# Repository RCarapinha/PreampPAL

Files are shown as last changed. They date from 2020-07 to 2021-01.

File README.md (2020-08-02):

# PreampPAL

Project done in 3th year of Masters.

# Description

The goal of this team is to perform a low-noise pre-amplifier that amplifies the needle signal to a line level signal. To accomplish this we started by understanding what was a preamplifier for a record player, namely, what was a preamplifier with reverse RIAA equalization that would amplify the needle signal to a line level signal.

So this team is responsible for the electronics of the turntable audio. This task consists of manipulating low-value and very sensitive voltages. 

# 1st Step: Tests and Simulation

Having said this, we started the search for a preamplifier that corresponded to our needs, i.e. a preamplifier that applied what was described above and low noise (because the values received by the needle are very low).

We chose a range of preamplifiers and set out for the simulation phase using the LTSpice program.

We performed several simulations in LTSpice in terms of noise and equalization in order to choose the best pre-amplifier. At the end of this phase we started to develop the circuit.

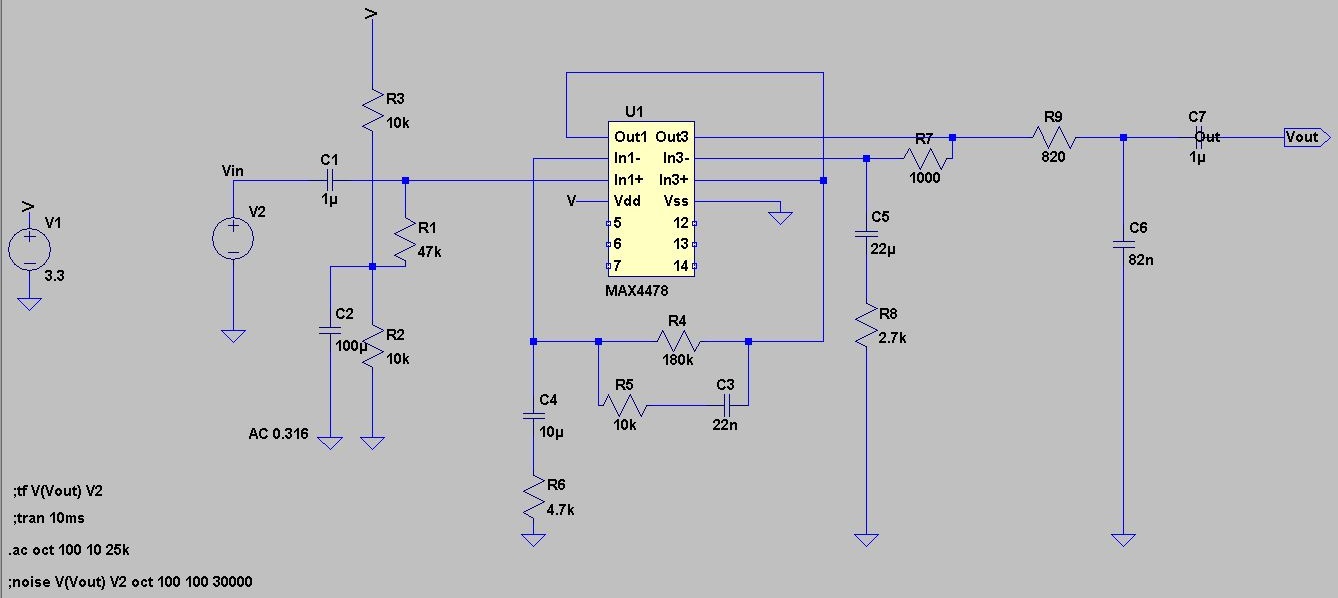
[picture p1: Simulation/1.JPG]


# 2nd Step: Breadboard Tests

The first test to be performed was to make sure that the voltage regulator (low noise) correctly converted the value from 5V to 3.3V, and this test was successful. The second test was to verify the amplification and RIAA equalization. For this, a weak signal was applied to the input and we compared the output values obtained with the theoretical output values.

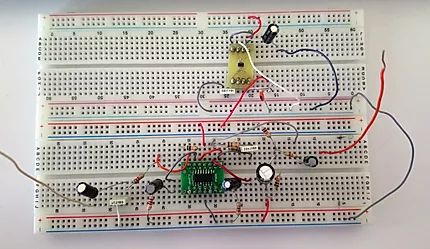
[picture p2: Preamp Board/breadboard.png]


# 3rd Step: PCB Design

After we carried out the tests and validated the operation of the circuit, the next step of the team was to develop the PCB (in EAGLE software) so that we could finish the work.

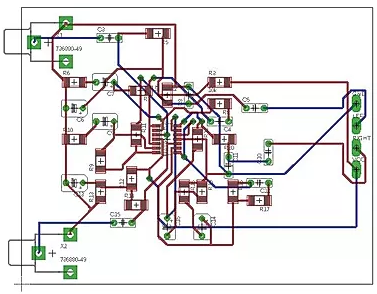
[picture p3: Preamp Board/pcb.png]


# 4rd Step: Final Work

Once the PCB has been designed, we start to build the board and assemble the components on it, something that must be done with great care to avoid errors or noise. Finally, we tried to isolate the whole board, for a better functioning.

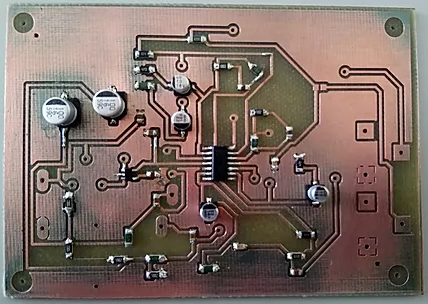
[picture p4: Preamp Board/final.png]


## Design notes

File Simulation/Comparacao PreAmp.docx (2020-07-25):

Comparação de Pré Amplificadores:

- Circuito:

Comparar entre 3 pré-amplificadores em termos de ganho, equalização RIAA, ruído, impedância de saída e preço e descobrir qual o mais viável.

- Circuitos Utilizados:
  - Bruno:

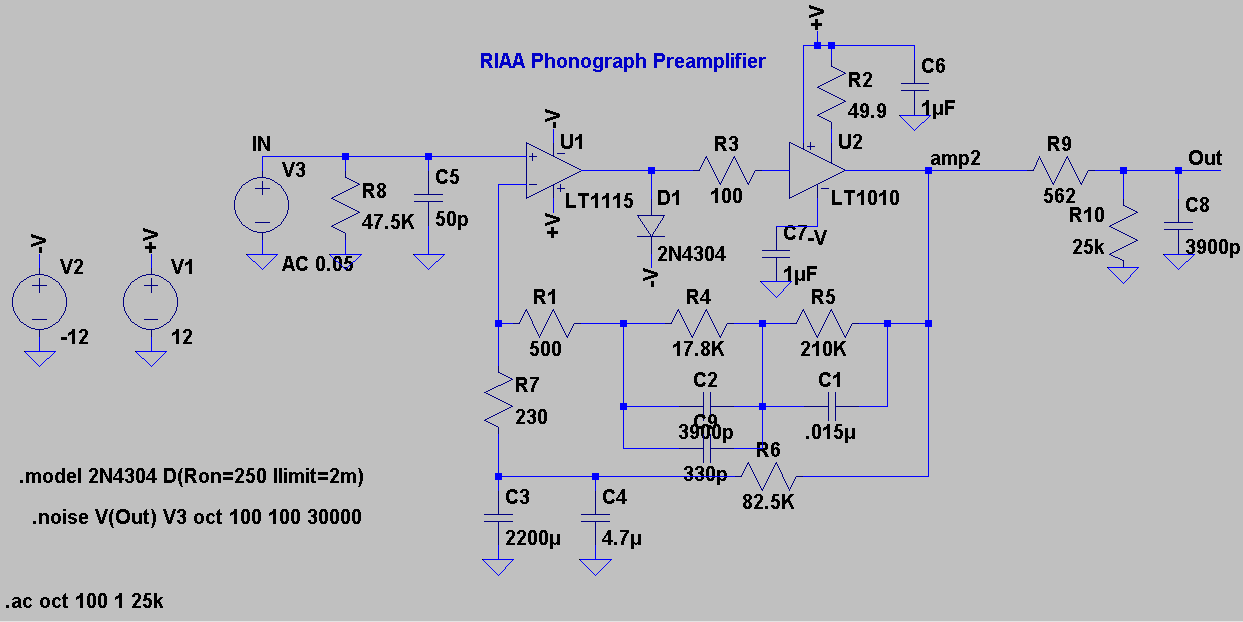
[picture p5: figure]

  - Carapinha:

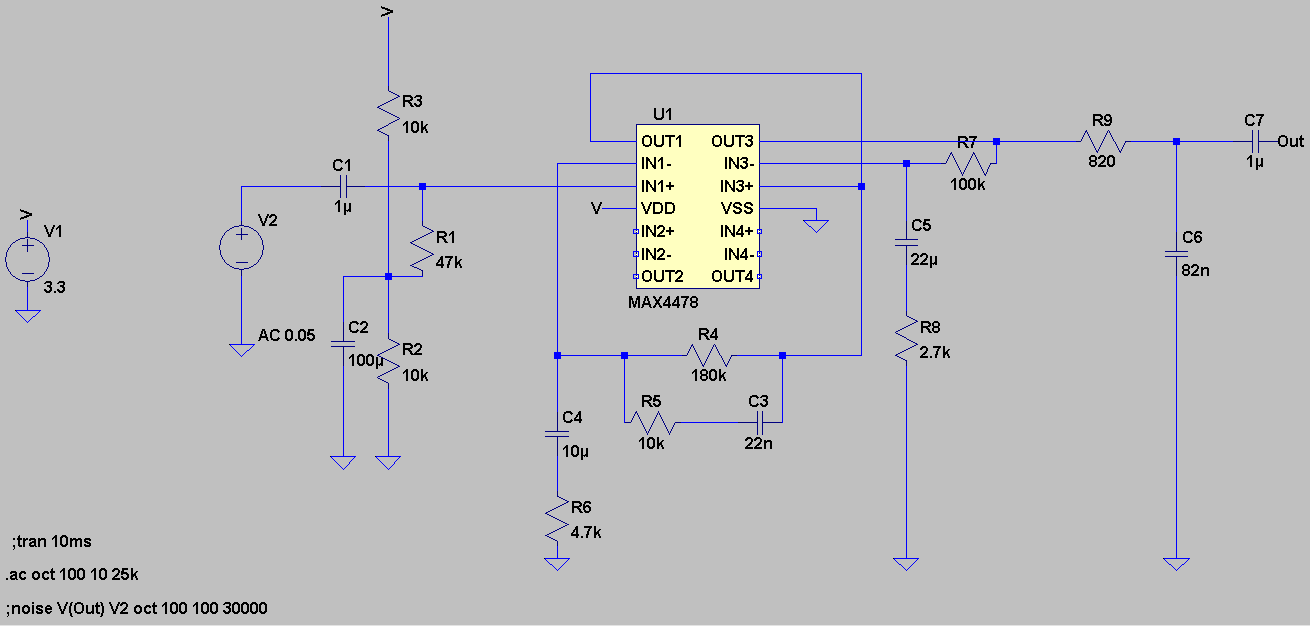
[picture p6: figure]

  - Gui:

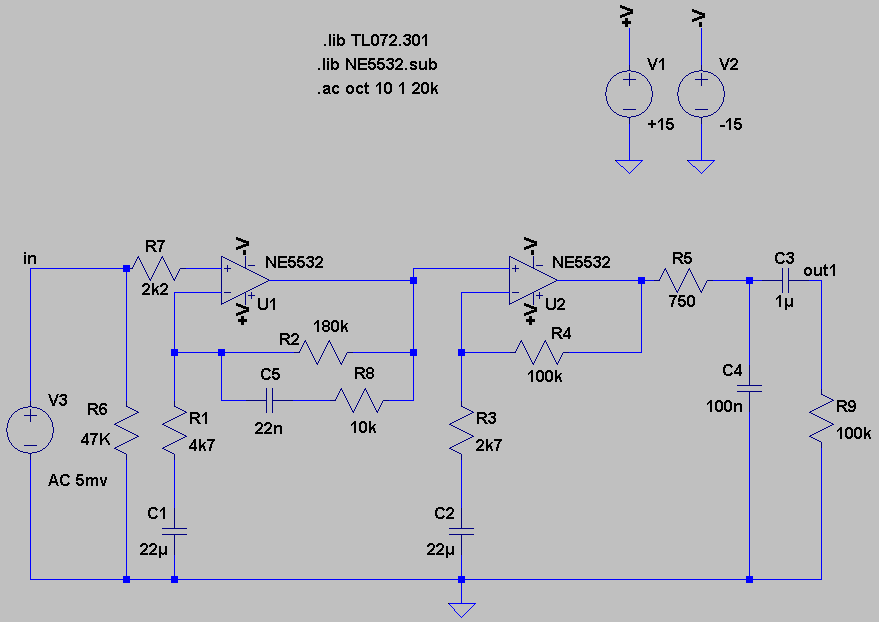
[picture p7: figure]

- RIAA:
  - Bruno:

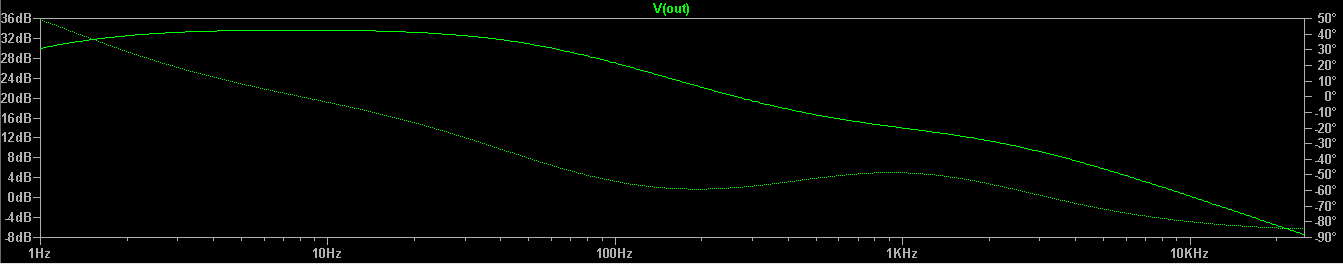
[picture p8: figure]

  - Carapinha:

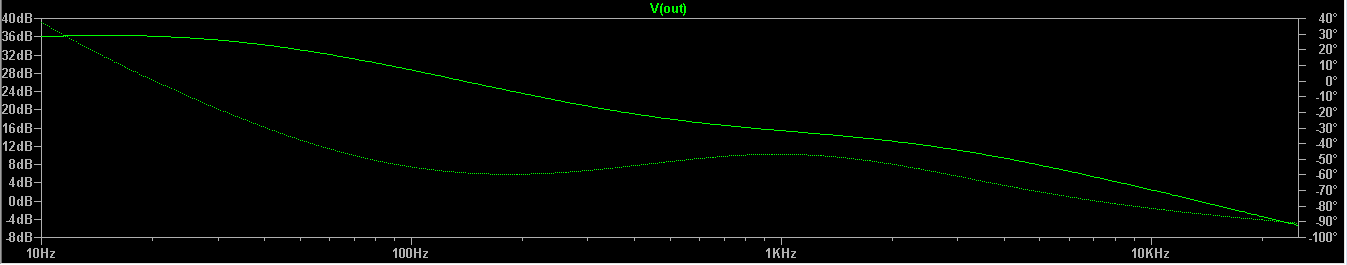
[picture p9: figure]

  - Gui:

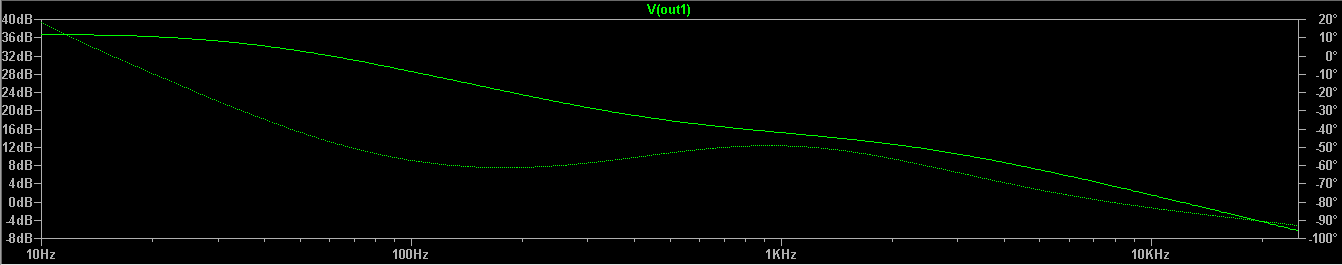
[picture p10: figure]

- Ruído:
  - Bruno:

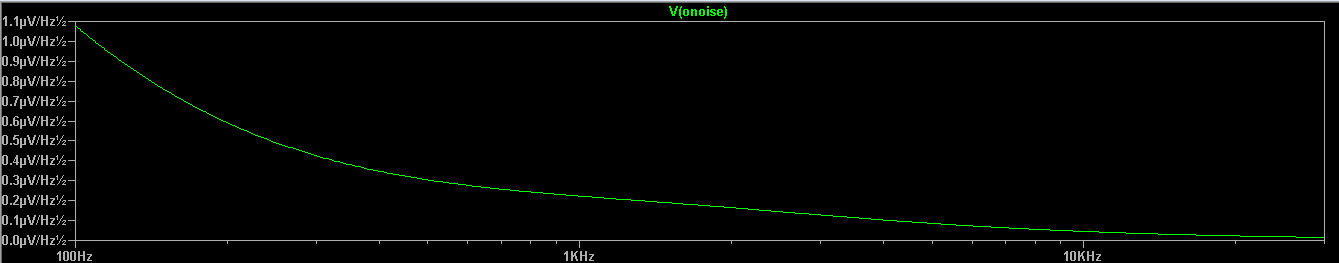
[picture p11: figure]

  - Carapinha:

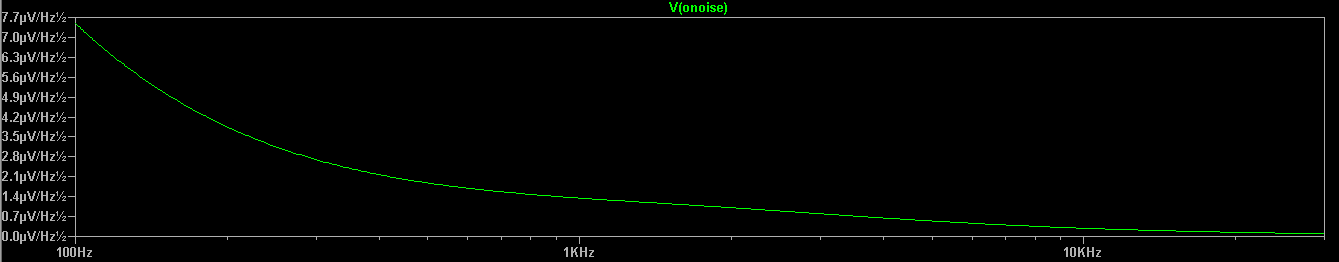
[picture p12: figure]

  - Gui:

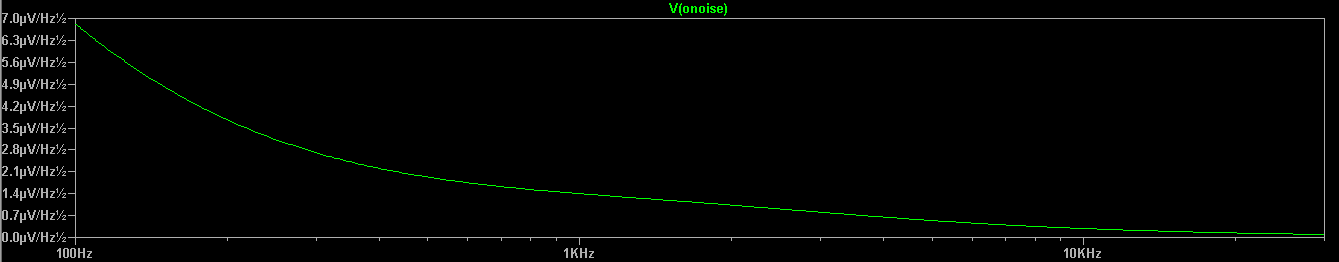
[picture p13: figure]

- Impedância de Saída:

Para fazer isto, colocámos uma fonte de corrente na saída e medimos a relação entre a tensão e a corrente.

  - Bruno:

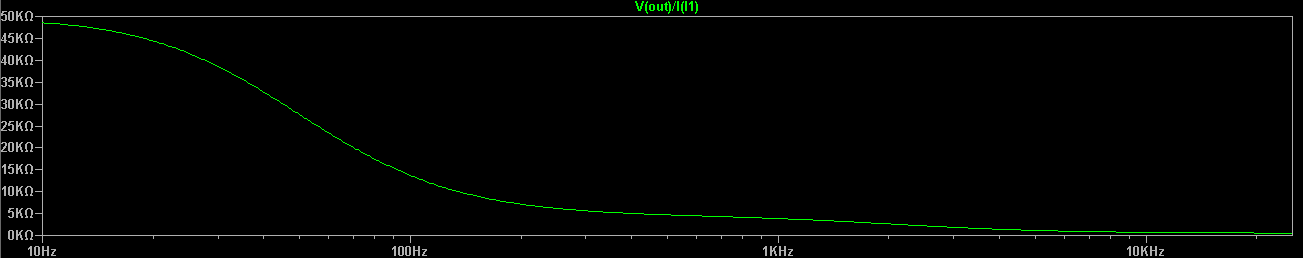
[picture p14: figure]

  - Carapinha:

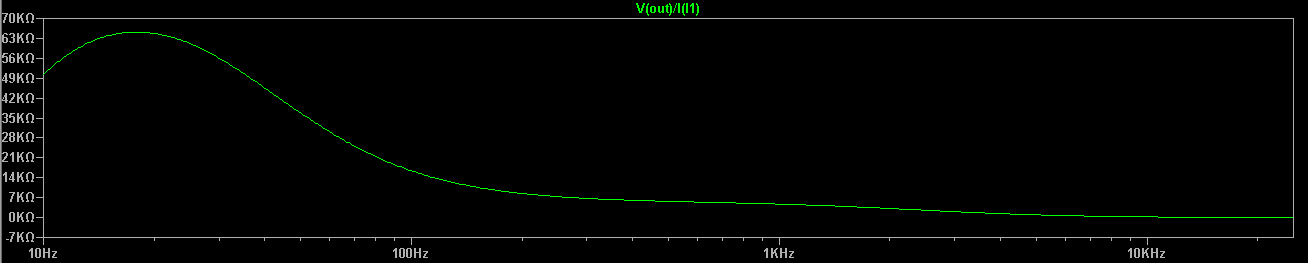
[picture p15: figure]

  - Gui:

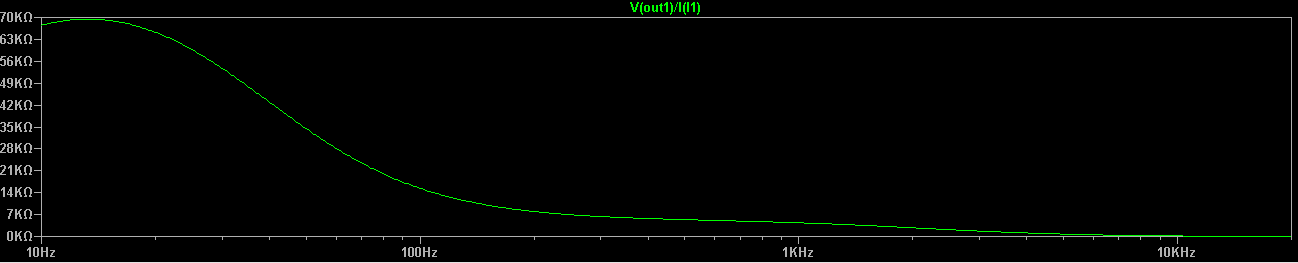
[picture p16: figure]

- Tensões Necessárias:
  - Bruno:

Tensões simétricas de 12V.

  - Carapinha:

Tensão única de 3.3V.

  - Gui:

Tensão simétricas de 15V.

- Preço:

Foram considerados os preços mais caros da loja DigiKey.

  - Bruno:

Componentes | Quantidade | Preço Unidade | Preço Total
R | 10 | 0,04 | 0,4
C | 13 | 0,2 | 2,6
LT1115 | 1 | 5,82 | 5,82
LT1010 | 1 | 4,57 | 4,57
Rail Splitter | 1 | - | -
2N4304 | 1 | - | -

Preço Total: 13,39€ (Faltam 2 componentes)

  - Carapinha:

Componentes | Quantidade | Preço Unidade | Preço Total
R | 9 | 0,04 | 0,36
C | 10 | 0,2 | 2
MAX4478 | 1 | 3,24 | 3,24
MAX8877EUK33 | 1 | 1,49 | 1,49

Preço Total: 7,09€

  - Gui:

Componentes | Quantidade | Preço Unidade | Preço Total
R | 9 | 0,04 | 0,36
C | 5 | 0,2 | 1
NE5532 | 1 | 1,26 | 1,26
Rail Splitter | 1 | - | -

Preço Total: 2,62€ (Falta 1 componente)

Os 3 circuitos precisam como é óbvio de um transformador de baixo ruído.

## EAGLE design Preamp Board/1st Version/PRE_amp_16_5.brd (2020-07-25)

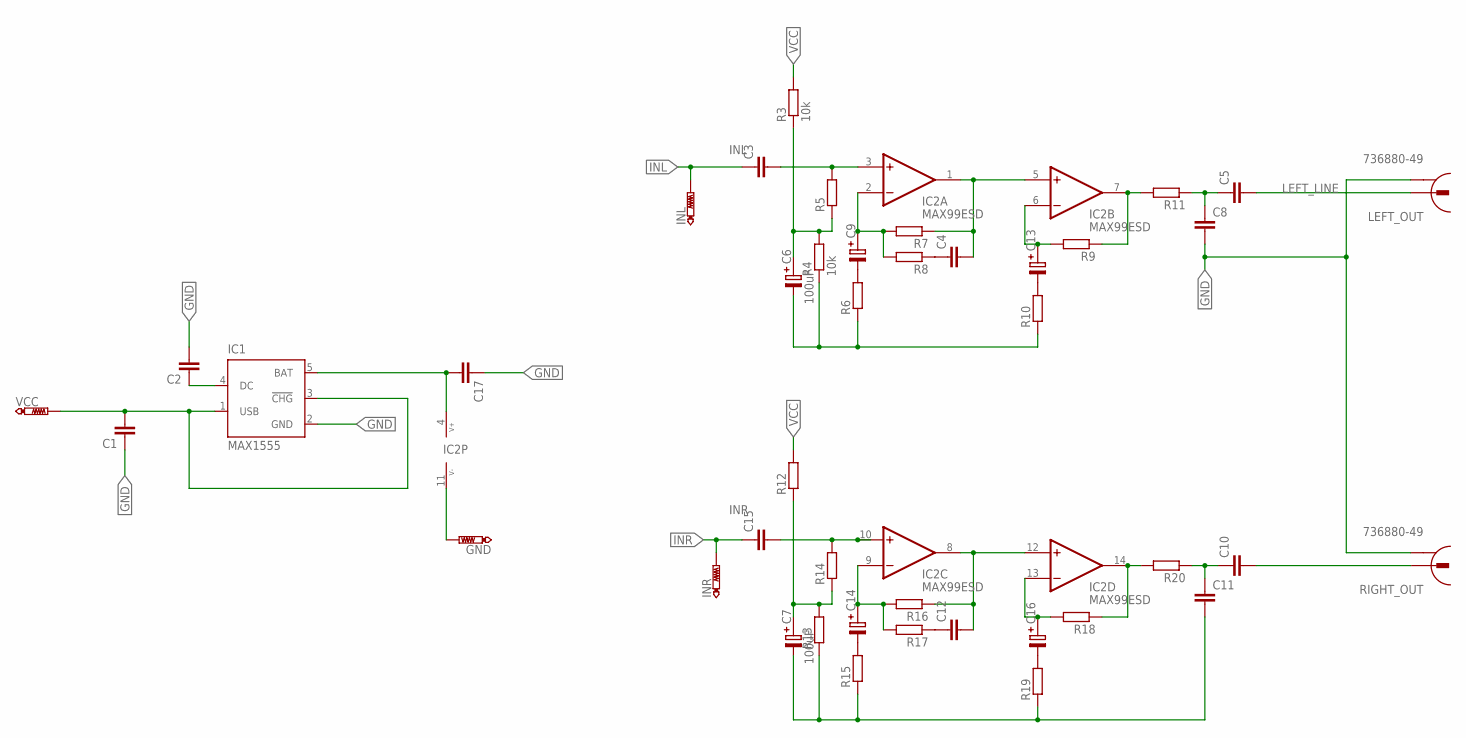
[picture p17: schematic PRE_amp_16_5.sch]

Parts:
C1, C2, C3, C4, C5, C8, C10, C11, C12, C15, C17: C-EUC0805; C0805
C6, C7: 100uF; SV-D
C9, C13, C14, C16: C-PR-SMD-SV-B; SV-B
GND: PTR1PAD1-13Y; P1-13Y
IC1: MAX1555; SOT23-5L
IC2: MAX99ESD; SO14
INL: PTR1PAD1-13Y; P1-13Y
INR: PTR1PAD1-13Y; P1-13Y
LEFT_OUT: 736880-49
R3, R4: 10k; R1206
R5, R6, R7, R8, R9, R10, R11, R12, R13, R14, R15, R16, R17, R18, R19, R20: R-EU_R1206; R1206
RIGHT_OUT: 736880-49
VCC: PTR1PAD1-13Y; P1-13Y

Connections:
GND: C1.1, C2.2, C6.-, C7.-, C8.2, C11.2, C17.1, GND.1, IC1.2 (GND), IC2.11 (V-), LEFT_OUT.2, R4.1, R6.1, R10.1, R13.1, R15.1, R19.1, RIGHT_OUT.2
INL: C3.1, INL.1
INR: C15.1, INR.1
LEFT_LINE: C5.2, LEFT_OUT.1
unnamed: C3.2, IC2.3 (+IN), R5.2
unnamed: C6.+, R3.1, R4.2, R5.1
unnamed: C15.2, IC2.10 (+IN), R14.2
unnamed: C7.+, R12.1, R13.2, R14.1
unnamed: IC2.7 (OUT), R9.1, R11.2
unnamed: C9.-, R6.2
unnamed: C4.1, R8.1
unnamed: C12.1, R17.1
unnamed: C9.+, IC2.2 (-IN), R7.2, R8.2
unnamed: C13.-, R10.2
unnamed: C5.1, C8.1, R11.1
unnamed: C14.-, R15.2
unnamed: C13.+, IC2.6 (-IN), R9.2
unnamed: C1.2, IC1.1 (USB), IC1.3 (!CHG), VCC.1
unnamed: C12.2, IC2.8 (OUT), IC2.12 (+IN), R16.1
unnamed: C14.+, IC2.9 (-IN), R16.2, R17.2
unnamed: C16.-, R19.2
unnamed: IC2.14 (OUT), R18.1, R20.2
unnamed: C4.2, IC2.1 (OUT), IC2.5 (+IN), R7.1
unnamed: C16.+, IC2.13 (-IN), R18.2
unnamed: C17.2, IC1.5 (BAT), IC2.4 (V+)
unnamed: C2.1, IC1.4 (DC)
unnamed: C10.2, RIGHT_OUT.1
NS2: C10.1, C11.1, R20.1
VCC: R3.2, R12.2

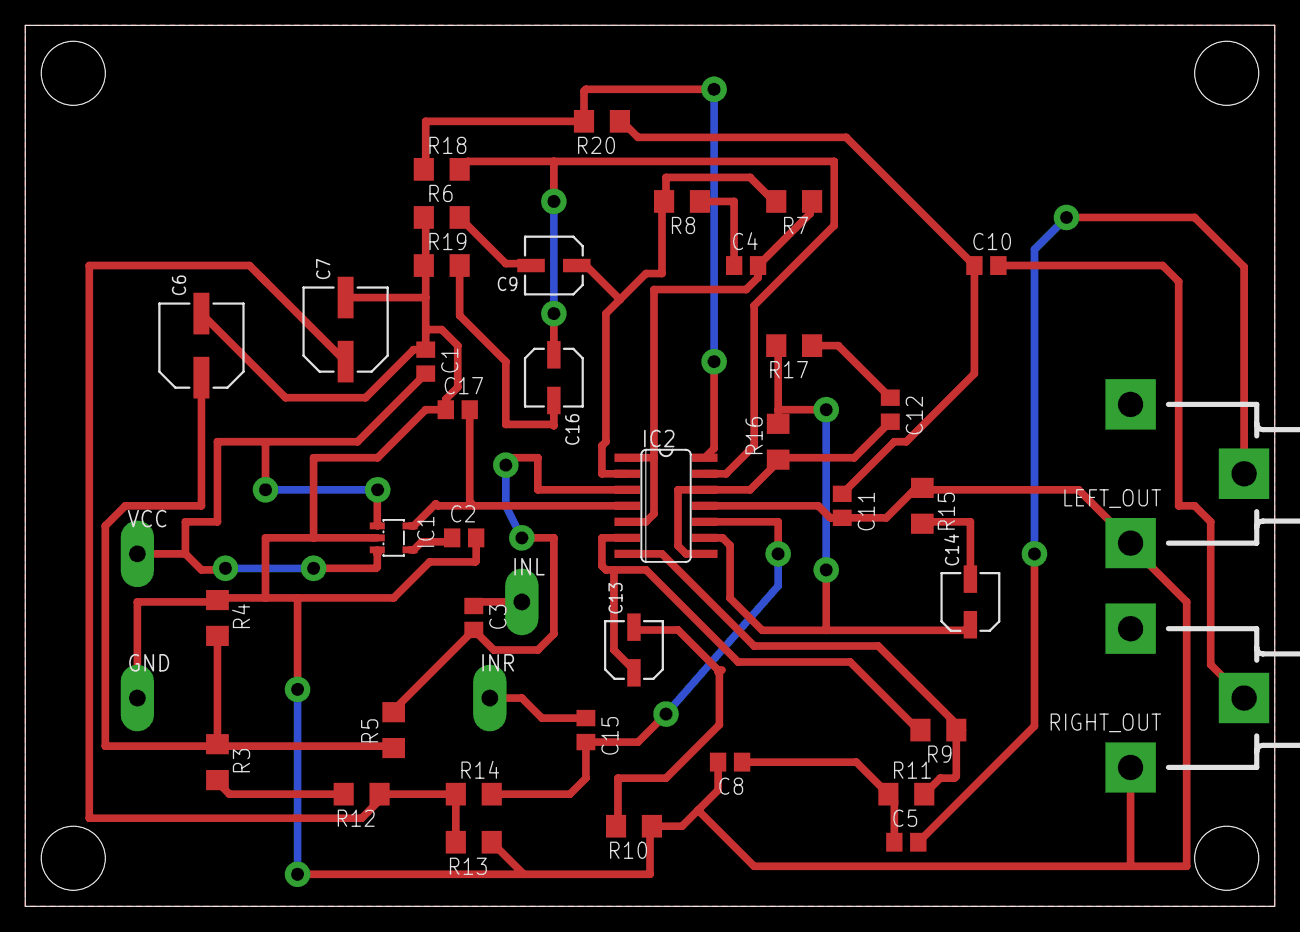
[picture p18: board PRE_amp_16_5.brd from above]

Board: 2 copper layers, 99.1 x 69.9 mm, 43 parts (0 on the bottom side), 29 nets.

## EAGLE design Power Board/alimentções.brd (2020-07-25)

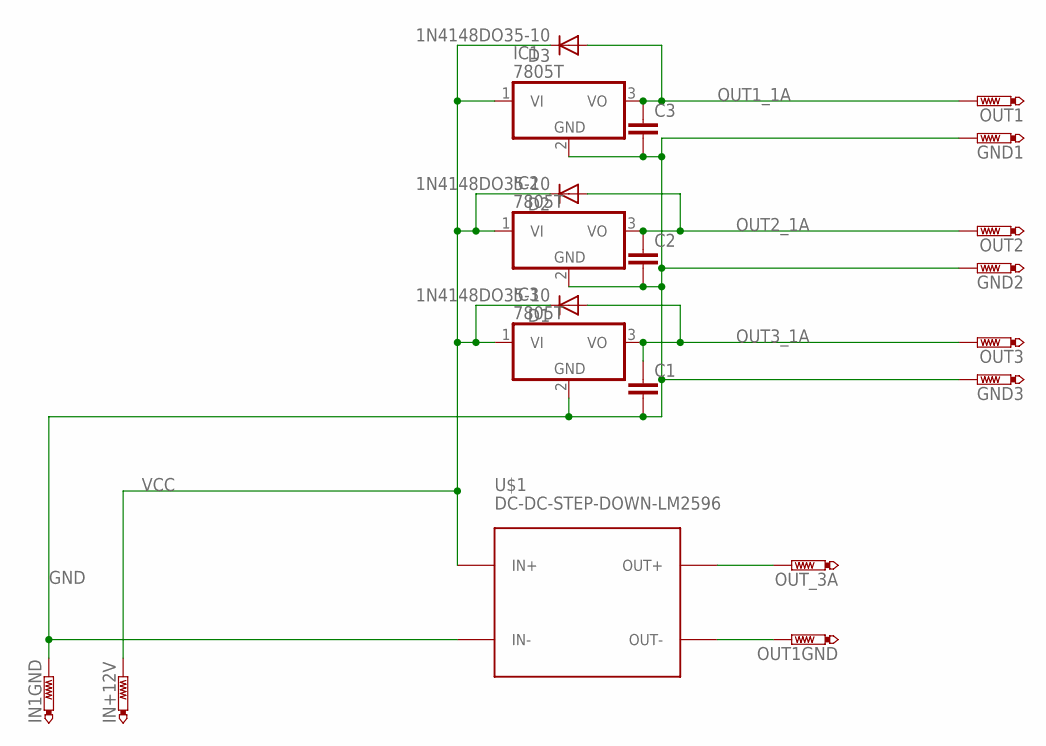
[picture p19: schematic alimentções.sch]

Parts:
C1, C2, C3: C-EU050-035X075; C050-035X075
D1, D2, D3: 1N4148DO35-10; DO35-10
GND1, GND2, GND3: PTR1PAD1-13Y; P1-13Y
IC1, IC2, IC3: 7805T; TO220H
IN1GND: PTR1PAD1-13Y; P1-13Y
IN+12V: PTR1PAD1-13Y; P1-13Y
OUT1, OUT1GND, OUT2, OUT3: PTR1PAD1-13Y; P1-13Y
OUT_3A: PTR1PAD1-13Y; P1-13Y
U$1: DC-DC-STEP-DOWN-LM2596

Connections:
GND: C1.2, C2.2, C3.2, GND1.TP, GND2.TP, GND3.TP, IC1.2 (GND), IC2.2 (GND), IC3.2 (GND), IN1GND.TP, U$1.IN-
unnamed: OUT1GND.TP, U$1.OUT-
unnamed: OUT_3A.TP, U$1.OUT+
OUT1_1A: C3.1, D3.A, IC1.3 (VO), OUT1.TP
OUT2_1A: C2.1, D2.A, IC2.3 (VO), OUT2.TP
OUT3_1A: C1.1, D1.A, IC3.3 (VO), OUT3.TP
VCC: D1.C, D2.C, D3.C, IC1.1 (VI), IC2.1 (VI), IC3.1 (VI), IN+12V.TP, U$1.IN+

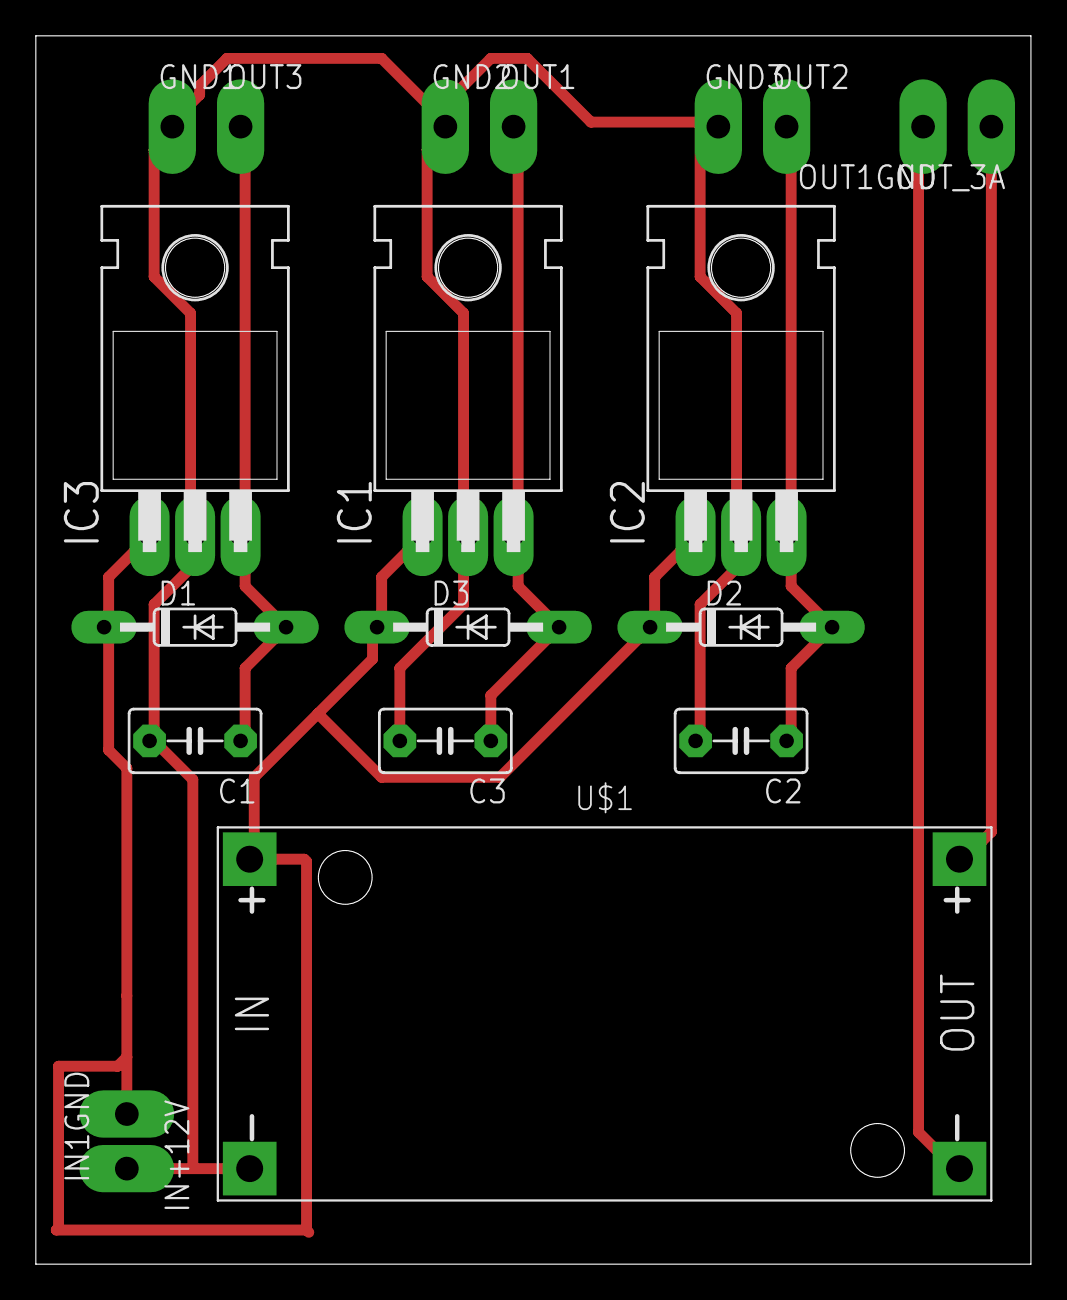
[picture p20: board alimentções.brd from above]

Board: 2 copper layers, 55.5 x 68.6 mm, 20 parts (0 on the bottom side), 7 nets.

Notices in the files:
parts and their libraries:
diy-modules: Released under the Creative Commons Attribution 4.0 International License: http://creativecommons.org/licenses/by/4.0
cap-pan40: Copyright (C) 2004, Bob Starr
